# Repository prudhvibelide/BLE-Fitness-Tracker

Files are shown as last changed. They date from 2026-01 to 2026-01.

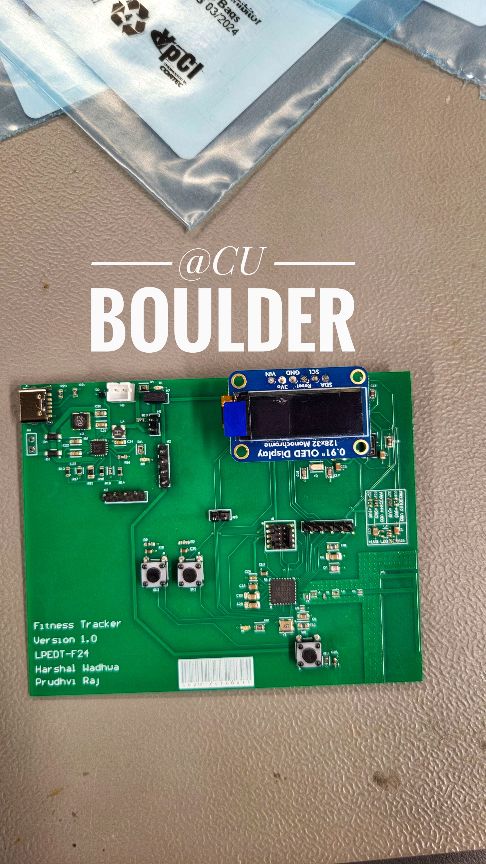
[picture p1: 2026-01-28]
PCB Board.jpg

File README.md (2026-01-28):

# BLE-Fitness-Tracker
Bluetooth based Smart Fitness Tracker using EFR32BG24 Chipset



# Developers
Prudhvi Raj Belide, Harshal Wadhwa

## Overview
This project is a bare-metal firmware bring-up for a custom wearable-style fitness tracker built around a Silicon Labs EFR32BG24. The firmware initializes board clocks and GPIO, communicates with multiple peripherals over I2C (IMU, temperature sensor, OLED), and exposes runtime telemetry over UART for validation and debugging. The goal is to prove a full embedded data path from sensor configuration and sampling to user-visible output on the display.

## Hardware
The prototype hardware is a custom PCB using an EFR32BG24 2.4 GHz SoC with I2C peripherals for sensing and display. The firmware is written to support typical wearable peripherals on the same I2C bus, including:
- Bosch BMA400 (accelerometer with step counting support)
- TI TMP117 (high-accuracy digital temperature sensor)
- SSD1306 128x64 OLED (I2C display controller)

## Firmware Summary
The firmware is implemented in C using Silicon Labs EMLIB and is structured around three layers.

Low-level drivers handle clock setup, GPIO routing, I2C transfers, and UART output. The I2C layer supports write, read, and write-then-read sequences suitable for register-mapped sensors and displays, with basic status checking and timeout protection.

Device drivers implement register-level configuration and data conversion. BMA400 is configured for periodic sampling and step counter operation, and TMP117 raw readings are converted to degrees Celsius. The SSD1306 driver writes a framebuffer to the display for stable rendering.

The application layer runs a periodic loop driven by a millisecond time base. It refreshes sensor data on a fixed cadence, updates the UI, and prints debug values over UART so you can verify I2C traffic and numeric conversions during bring-up.

## Toolchain
This project targets Silicon Labs Gecko SDK with Simplicity Studio 5.

Required:
1) Simplicity Studio 5
2) Gecko SDK for the EFR32BG24 family
3) A debug probe (onboard debugger or external) for flashing and SWD debug

## Build and Flash
Open the project in Simplicity Studio 5, make sure the correct target device is selected (EFR32BG24), then build the project using the IDE build button. Flash using the built-in Flash Programmer or by clicking Run.

If you use the command line flow, generate the project from the Simplicity Configurator (if applicable), then build with the generated project settings for your toolchain. The exact CLI steps depend on how your Simplicity project was created.

## Run and Verify
After flashing, power the board (USB-C or your board’s supply rail). The OLED should initialize and show live values such as steps and temperature if the sensors are detected on I2C.

UART is used for bring-up logs and sensor validation. Use a serial terminal at 115200 baud, 8-N-1. On Linux, a typical command looks like:
`screen /dev/ttyACM0 115200`

If you do not see logs, confirm the correct UART pins are routed in GPIO/USART configuration and that your board’s USB-UART (or external adapter) shares ground with the PCB.

## Configuration Notes
I2C device addresses, update intervals, and sampling configuration are defined in the driver/config headers. If you change the IMU range, output data rate, or step-count settings, keep the application update rate consistent with the sensor configuration so you avoid aliasing and confusing results.

If the OLED remains blank, validate the I2C pull-ups, confirm the OLED address (commonly 0x3C), and verify that the initialization sequence matches your display module.

## Repository Layout
`app.c` contains the main application loop, periodic update logic, and high-level orchestration.
`i2c_code.c/.h` contains the reusable I2C transaction layer used by all peripherals.
Other files provide board initialization, peripheral setup, and any device-specific register definitions.

## Known Limitations
This is a bring-up focused firmware and does not implement full wearable power management. For a production wearable, you would typically add deeper sleep states, interrupt-driven sampling, sensor FIFO usage where available, and aggressive duty cycling of peripherals.

## License
Use the license required by your course or team policy. If you are using Silicon Labs SDK sources, retain their headers and licensing terms where applicable.

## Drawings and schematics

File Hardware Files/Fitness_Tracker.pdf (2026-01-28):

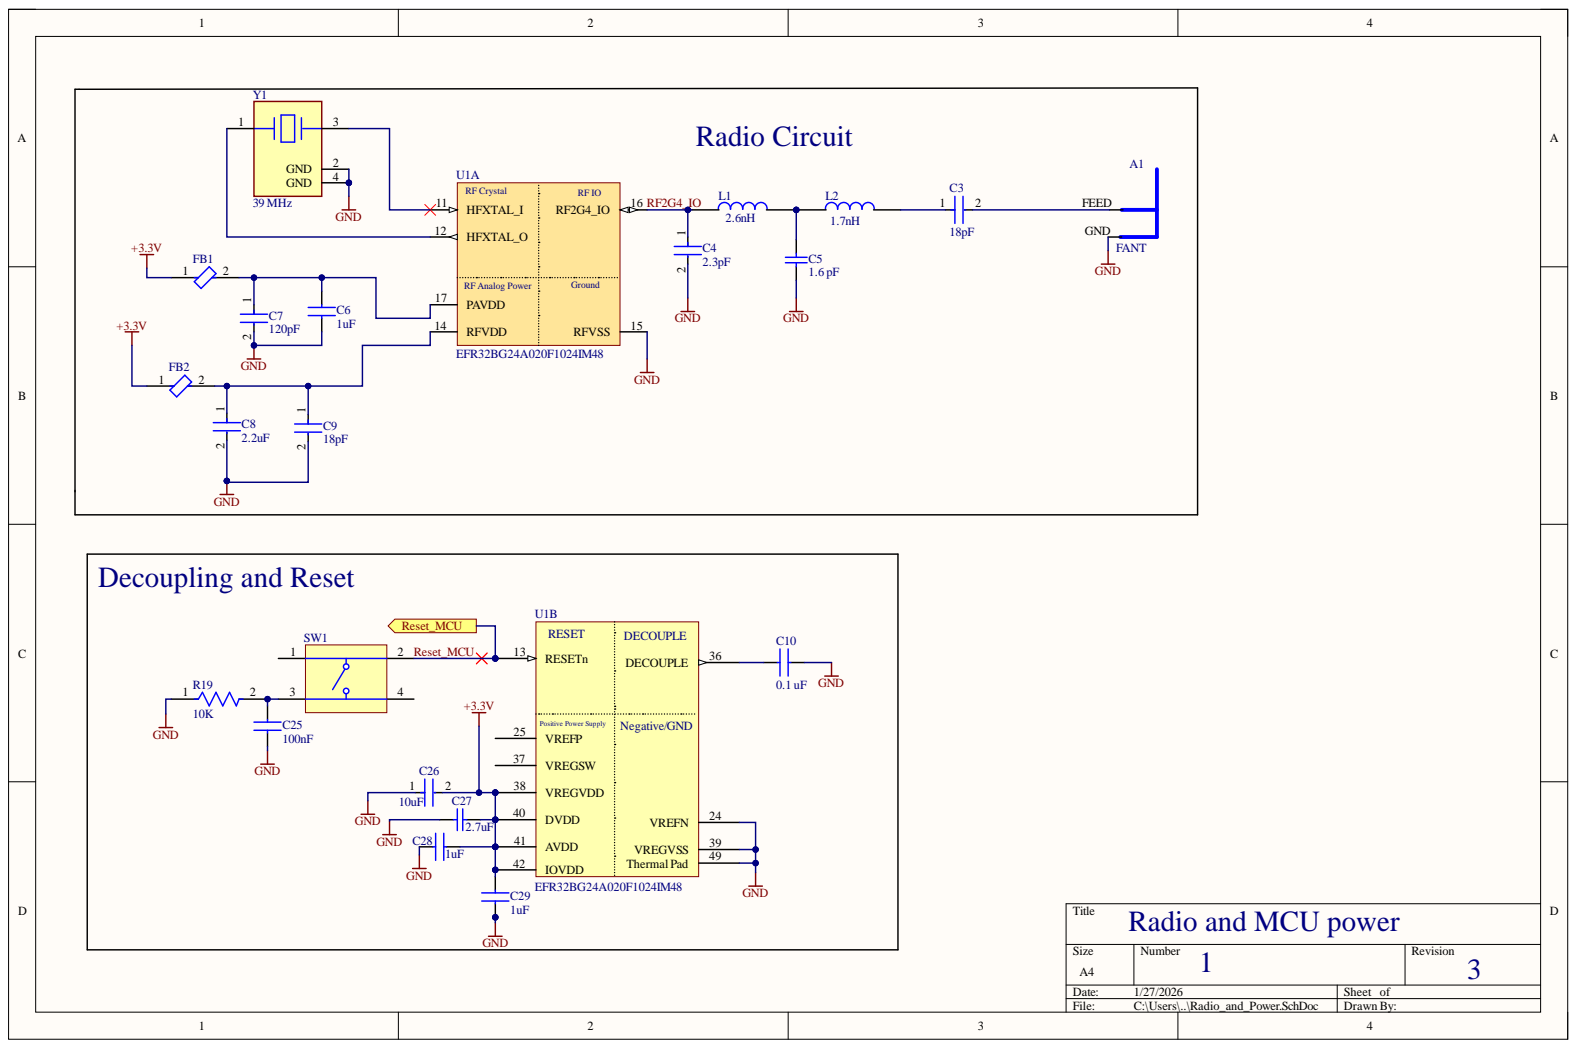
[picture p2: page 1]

Title
Radio and MCU power

Size A4 | Number 1 | Revision 3

Date: 1/27/2026 | Sheet of
File: C:\Users\..\Radio_and_Power.SchDoc | Drawn By:

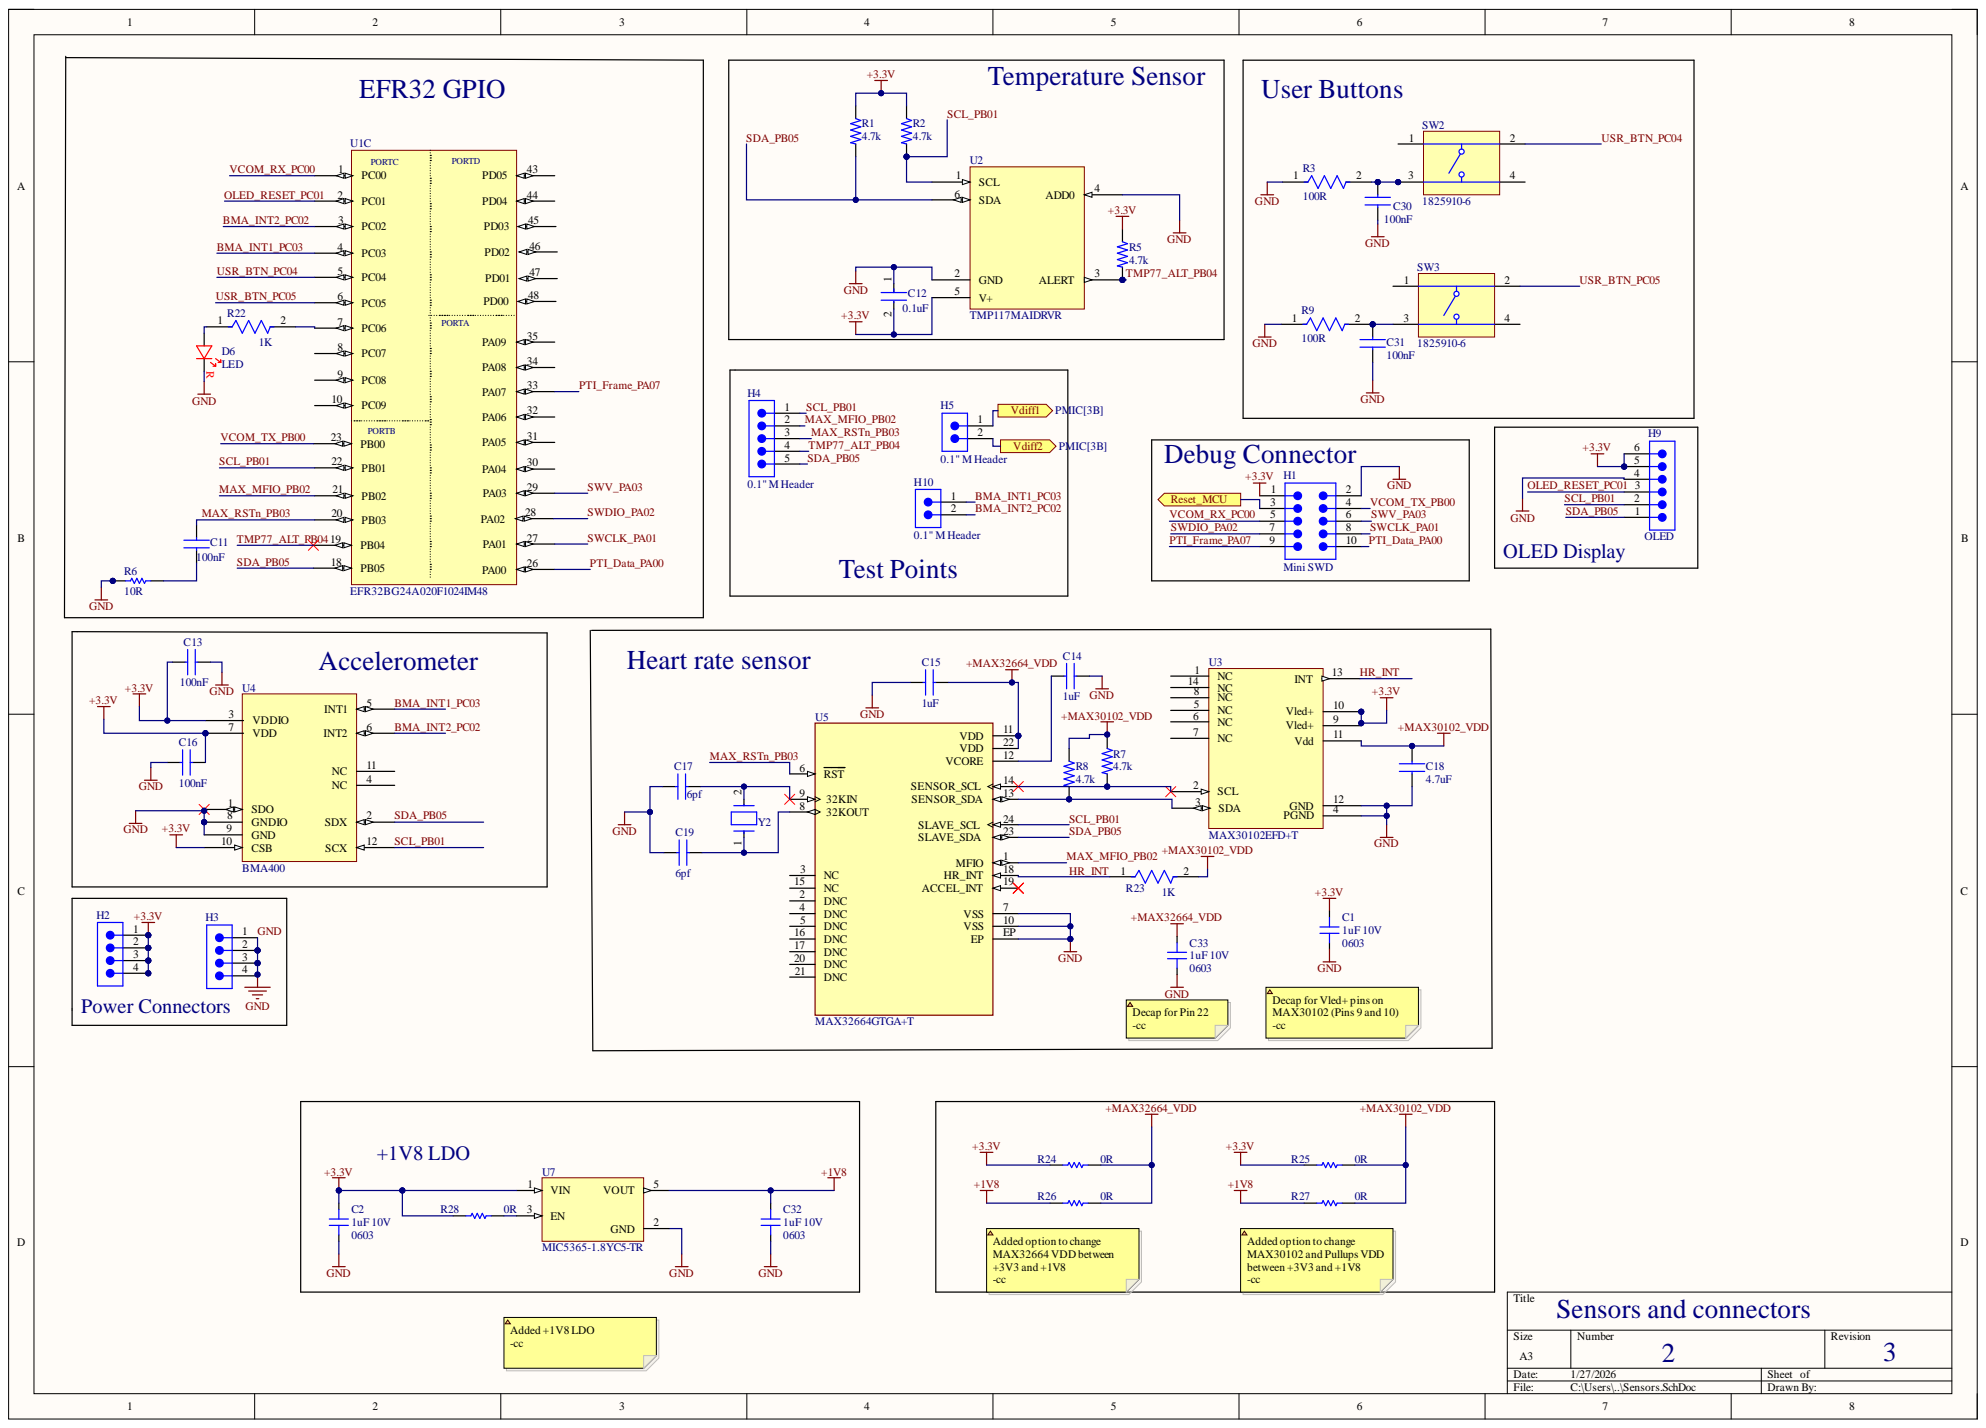
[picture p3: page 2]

Decap for Vled+ pins on
MAX30102 (Pins 9 and 10)

Added option to change
MAX30102 and Pullups VDD
between +3V3 and +1V8

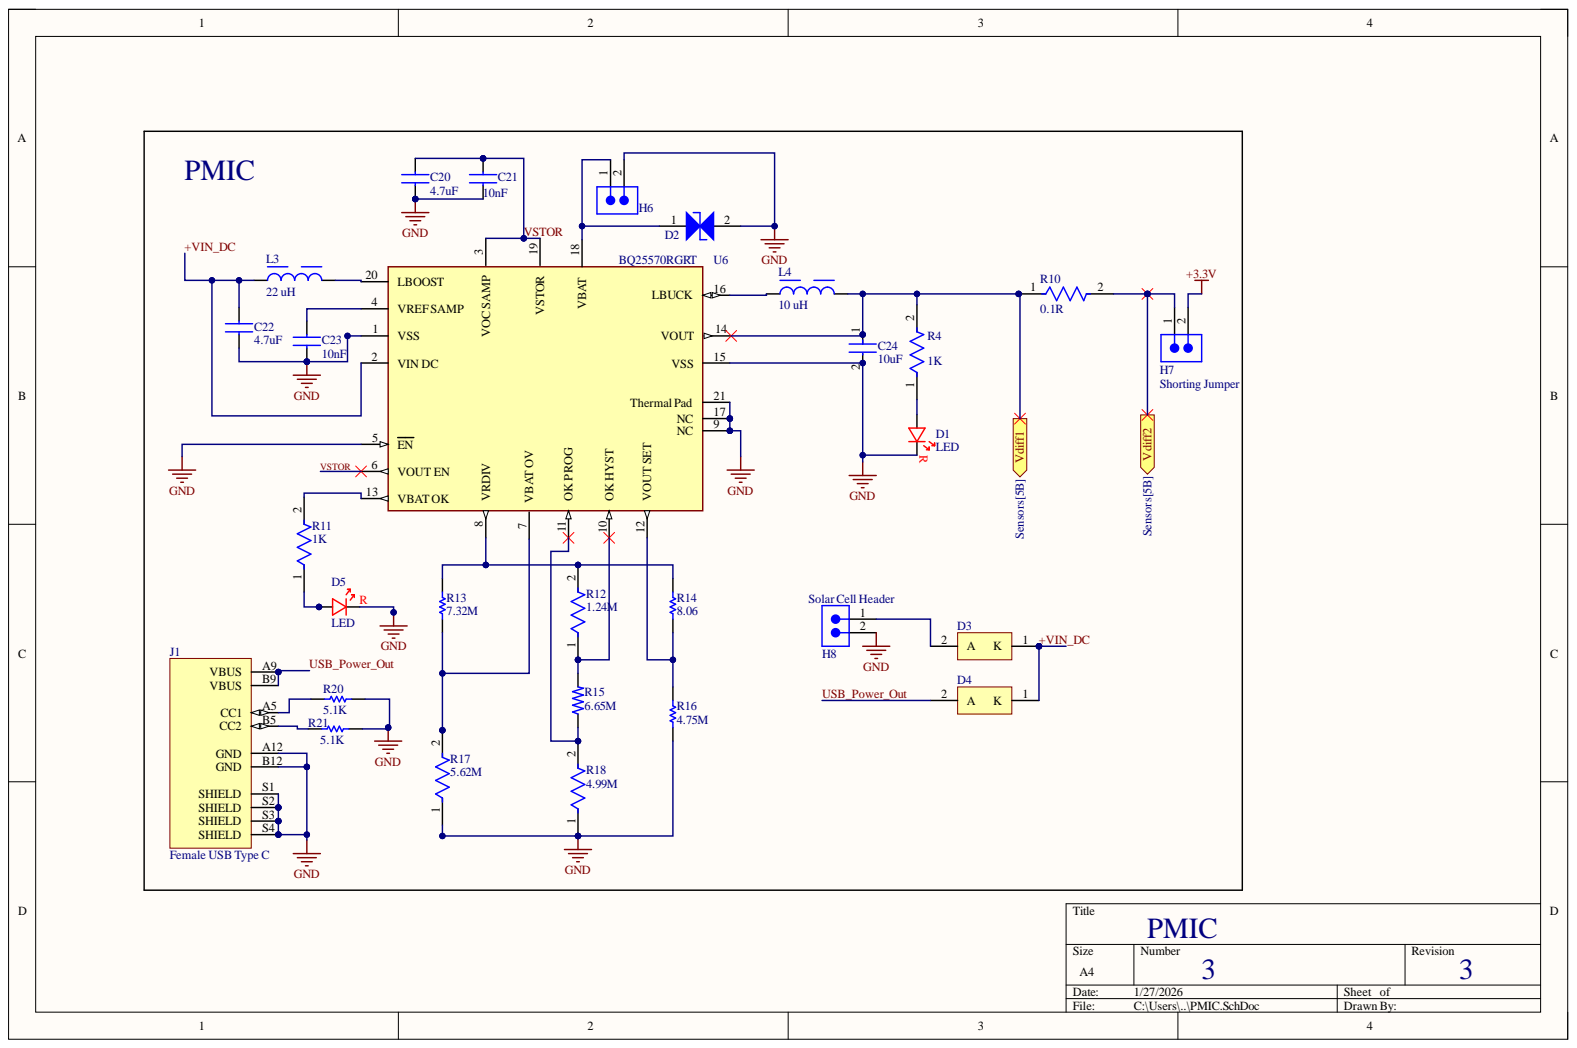
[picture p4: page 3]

Siz e A4 | Numb e r | R evisio n 3

Da te : 1/27/202 6 | She et of
File : C:\Use rs\. .\PMI C . S c hD o c | Dr awn B y :

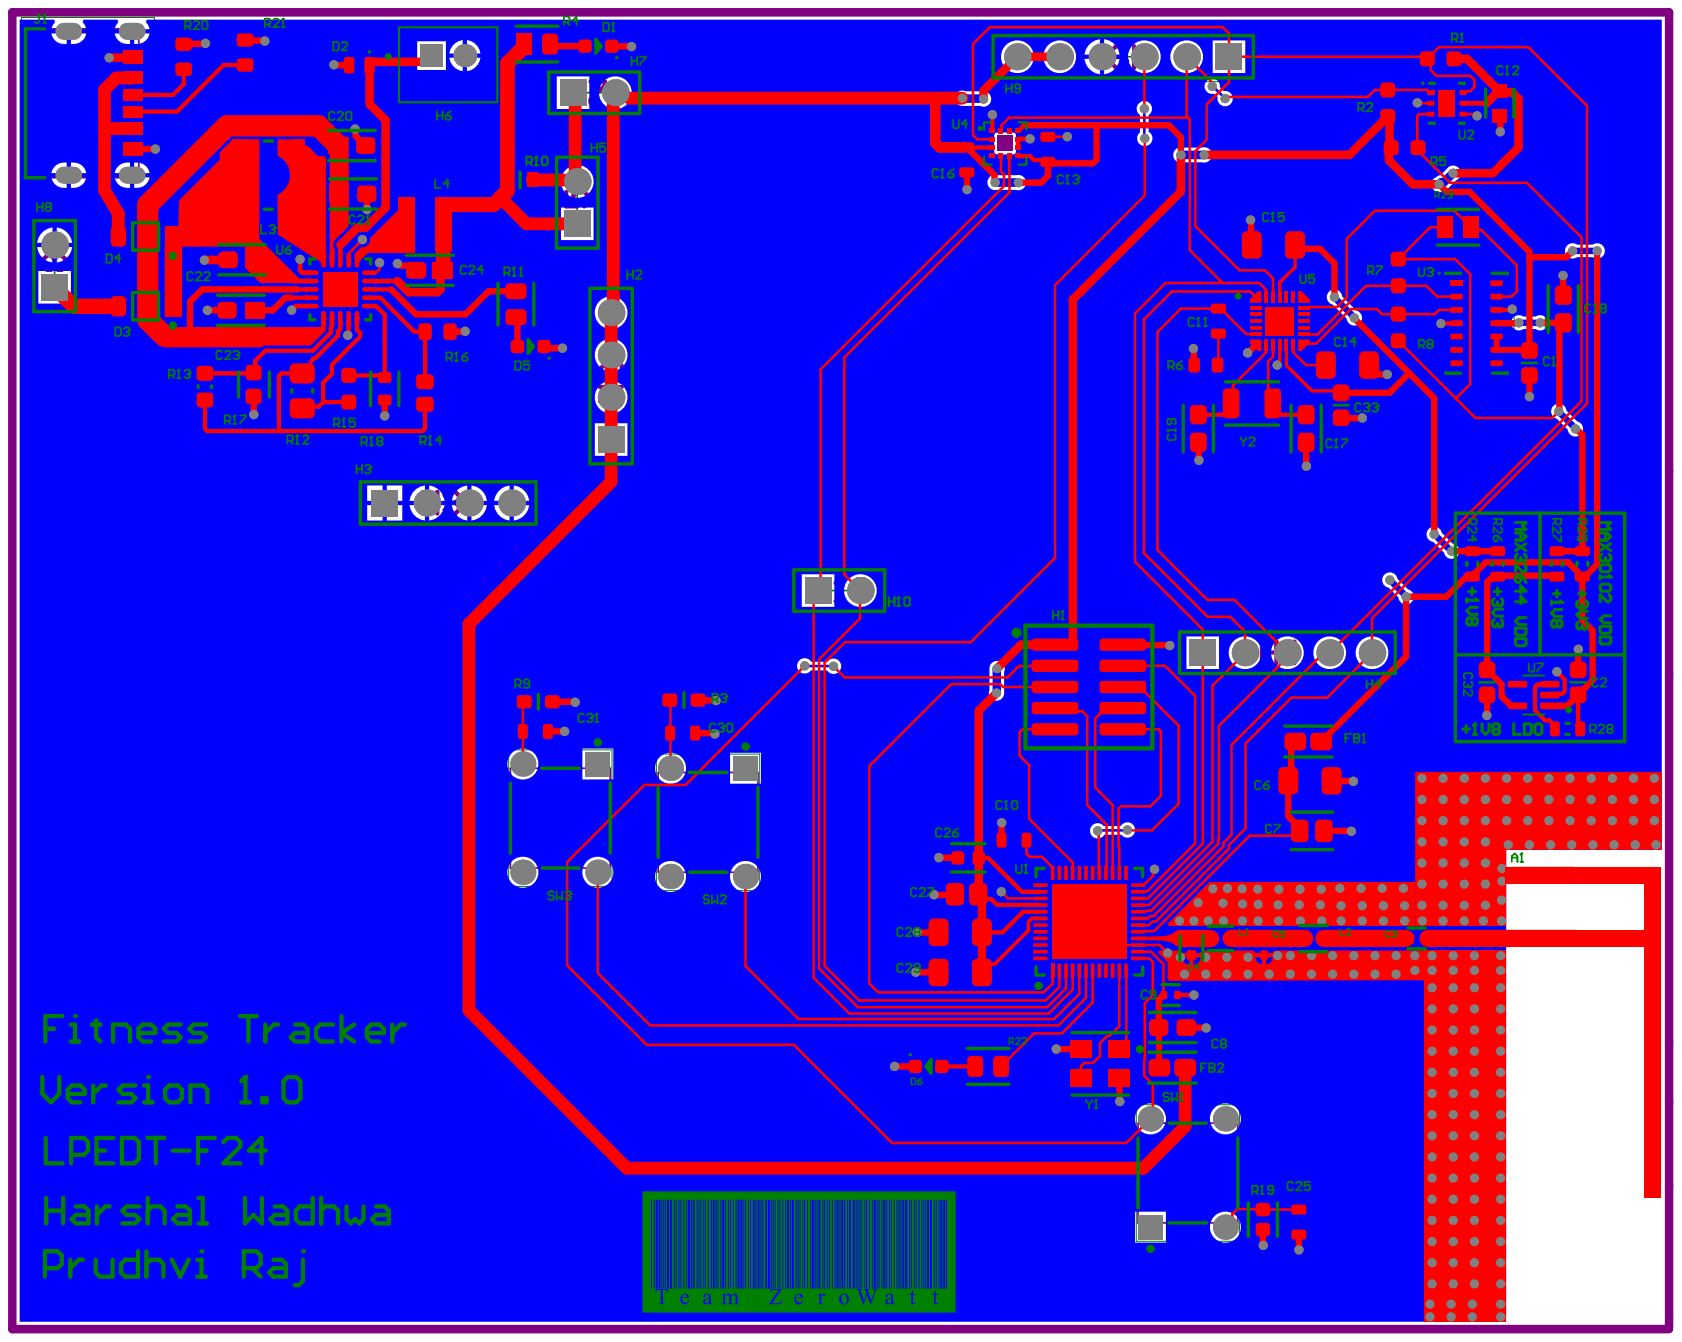
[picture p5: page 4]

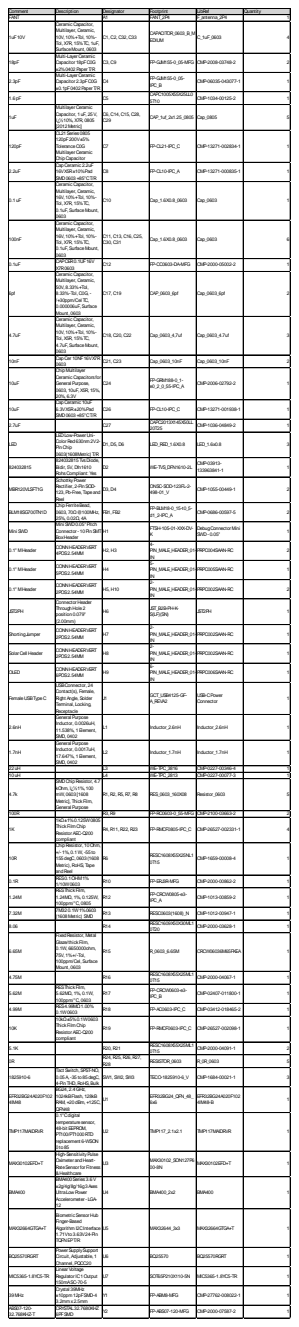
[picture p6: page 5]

1uF10V | Ceramic Capacitor, Multilayer, Ceramic, 10V, 10%+Tol, 10%-Tol, X7R, 15%TC, 1uF, SurfaceMount, 0603 | C1, C2, C32, C33 | CAPACITOR_0603_B_M EDIUM | C_1uF_0603 | 4

18pF | Multi-Layer Ceramic Capacitor 18pFC0G ±2%0402PaperT/R | C3, C9 | FP-GJM155-0_05-MFG | CMP-2008-03748-2 | 2

2.3pF | Multi-Layer Ceramic Capacitor 2.3pFC0G ±0.1pF0402PaperT/R | C4 | FP-GJM155-0_05-IPC_B | CMP-06035-043077-1 | 1

1.6pF | | C5 | CAPC1005X55X25LL0 5T10 | CMP-1034-00125-2 | 1

1uF | Multilayer Ceramic Capacitor, 1uF, 25V, ï¿½10%, X7R, 0805 [2012Metric] | C6, C14, C15, C28, C29 | CAP_1uf_2x1.25_0805 | Cap_0805 | 5

120pF | CL21Series0805 120pF200V±5% ToleranceC0G Multilayer Ceramic ChipCapacitor | C7 | FP-CL21-IPC_C | CMP-13271-002834-1 | 1

2.2uF | CapCeramic 2.2uF 16VX5R±10%Pad SMD0603+85°CT/R | C8 | FP-CL10-IPC_A | CMP-13271-000835-1 | 1

0.1uF | Ceramic Capacitor, Multilayer, Ceramic, 16V, 10%+Tol, 10%-Tol, X7R, 15%TC, 0.1uF, SurfaceMount, 0603 | C10 | Cap_1.6X0.8_0603 | Cap_0603 | 1

100nF | Ceramic Capacitor, Multilayer, Ceramic, 16V, 10%+Tol, 10%-Tol, X7R, 15%TC, 0.1uF, SurfaceMount, 0603 | C11, C13, C16, C25, C30, C31 | Cap_1.6X0.8_0603 | Cap_0603 | 6

0.1uF | CAPCER0.1UF16V X7R0603 | C12 | FP-CC0603-DA-MFG | CMP-2000-05002-2 | 1

6pf | Ceramic Capacitor, Multilayer, Ceramic, 50V, 8.33%+Tol, 8.33%-Tol, C0G, -/+30ppm/Cel TC, 0.000006uF, Surface Mount, 0603 | C17, C19 | CAP_0603_6pf | Cap_0603_6pf | 2

4.7uF | Ceramic Capacitor, Multilayer, Ceramic, 10V, 10%+Tol, 10%-Tol, X5R, 15%TC, 4.7uF, SurfaceMount, 0603 | C18, C20, C22 | Cap_0603_4,7uf | Cap_0603_4.7uf | 3

10nF | CapCer 10NF16VX7R 0603 | C21, C23 | Cap_0603_10nF | Cap_0603_10nF | 2

10uF | ChipMultilayer Ceramic Capacitorsfor General Purpose, 0603, 10uF, X5R, 15%, 20%, 6.3V | C24 | FP-GRM188-0_1-e0_2_0_55-IPC_A | CMP-2006-02792-2 | 1

10uF | CapCeramic 10uF 6.3VX5R±20%Pad SMD0603+85°CT/R | C26 | FP-CL10-IPC_C | CMP-13271-001938-1 | 1

2.7uF | | C27 | CAPC2013X145X50LL 20T25 | CMP-1036-04849-2 | 1

LED | LEDLow-Power Uni-Color Red630nm2V2-PinChip 0603(1608Metric)T/R | D1, D5, D6 | LED_RED_1.6X0.8 | LED_1.6x0.8 | 3

824032815 | 824032815TvsDiode, Bidir, 5V, Dfn1610 RohsCompliant: Yes | D2 | WE-TVS_DFN1610-2L | CMP-03913-133963841-1 | 1

MBR120VLSFT1G | SchottkyPower Rectifier, 2-PinSOD-123, Pb-Free, Tapeand Reel | D3, D4 | ONSC-SOD-123FL-2-498-01_V | CMP-1055-00449-1 | 2

BLM18SG700TN1D | ChipFerriteBead, 0603, 70Ω@100MHz, 25%, 0.02Ω, 4A | FB1, FB2 | FP-BLM18-0_15-t0_5-d1_2-IPC_A | CMP-0686-00597-5 | 2

Mini SWD | Mini SWD0.05"Pitch Connector- 10PinSMT BoxHeader | H1 | FTSH-105-01-XXX-DV-K | DebugConnector Mini SWD- 0.05" | 1

0.1" MHeader | CONNHEADERVERT 4POS2.54MM | H2, H3 | 4-PIN_MALE_HEADER_01-IN | PRPC004SAAN-RC | 2

0.1" MHeader | CONNHEADERVERT 5POS2.54MM | H4 | 5-PIN_MALE_HEADER_01-IN | PRPC005SAAN-RC | 1

0.1" MHeader | CONNHEADERVERT 2POS2.54MM | H5, H10 | 2-PIN_MALE_HEADER_01-IN | PRPC002SAAN-RC | 2

JST2PH | Connector Header ThroughHole2 position0.079" (2.00mm) | H6 | JST_B2B-PH-K-S(LF)(SN) | JST2PH | 1

ShortingJumper | CONNHEADERVERT 2POS2.54MM | H7 | 2-PIN_MALE_HEADER_01-IN | PRPC002SAAN-RC | 1

Solar Cell Header | CONNHEADERVERT 2POS2.54MM | H8 | 2-PIN_MALE_HEADER_01-IN | PRPC002SAAN-RC | 1

OLED | CONNHEADERVERT 6POS2.54MM | H9 | 6-PIN_MALE_HEADER_01-IN | PRPC006SAAN-RC | 1

FemaleUSBTypeC | USBConnector, 24 Contact(s), Female, Right Angle, Solder Terminal, Locking, Receptacle | J1 | GCT_USB4125-GF-A_REVA2 | USB-CPower Connector | 1

2.6nH | General Purpose Inductor, 0.0026uH, 11.538%, 1Element, SMD, 0402 | L1 | Inductor_2.6nH | Inductor_2.6nH | 1

1.7nH | General Purpose Inductor, 0.0017uH, 17.647%, 1Element, SMD, 0402 | L2 | Inductor_1.7nH | Inductor_1.7nH | 1

22uH | | L3 | WE-TPC_3816 | CMP-0227-00346-4 | 1
10uH | | L4 | WE-TPC_2813 | CMP-0227-00077-3 | 1
4.7k | SMDChipResistor, 4.7 kOhm, ï¿½1%, 100 mW, 0603[1608 Metric], ThickFilm, General Purpose | R1, R2, R5, R7, R8 | RES_0603_160X08 | Resistor_0603 | 5

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

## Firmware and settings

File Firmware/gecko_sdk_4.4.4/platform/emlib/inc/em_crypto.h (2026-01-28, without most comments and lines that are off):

#define EM_CRYPTO_H
#include "em_device.h"
# if defined(__GNUC__)
#  define CRYPTO_WARNINGS_NO_CAST_ALIGN \
  _Pragma("GCC diagnostic push")        \
  _Pragma("GCC diagnostic ignored \"-Wcast-align\"")
#  define CRYPTO_WARNINGS_RESET \
  _Pragma("GCC diagnostic pop")
# else
#  define CRYPTO_WARNINGS_NO_CAST_ALIGN
#  define CRYPTO_WARNINGS_RESET
# endif
#if defined(CRYPTO_COUNT) && (CRYPTO_COUNT > 0)
#include "em_bus.h"
#include "sl_common.h"
#include "em_crypto_compat.h"
#include <stdbool.h>
#include <string.h>
#ifdef __cplusplus
extern "C" {
#endif
#if defined(CRYPTO)
#define DEFAULT_CRYPTO CRYPTO
#elif defined(CRYPTO0)
#define DEFAULT_CRYPTO CRYPTO0
#endif
#define CRYPTO_DATA_SIZE_IN_BITS           (128)
#define CRYPTO_DATA_SIZE_IN_BYTES          (CRYPTO_DATA_SIZE_IN_BITS / 8)
#define CRYPTO_DATA_SIZE_IN_32BIT_WORDS    (CRYPTO_DATA_SIZE_IN_BYTES / sizeof(uint32_t))
#define CRYPTO_KEYBUF_SIZE_IN_BITS         (256)
#define CRYPTO_KEYBUF_SIZE_IN_BYTES        (CRYPTO_DDATA_SIZE_IN_BITS / 8)
#define CRYPTO_KEYBUF_SIZE_IN_32BIT_WORDS  (CRYPTO_DDATA_SIZE_IN_BYTES / sizeof(uint32_t))
#define CRYPTO_DDATA_SIZE_IN_BITS          (256)
#define CRYPTO_DDATA_SIZE_IN_BYTES         (CRYPTO_DDATA_SIZE_IN_BITS / 8)
#define CRYPTO_DDATA_SIZE_IN_32BIT_WORDS   (CRYPTO_DDATA_SIZE_IN_BYTES / sizeof(uint32_t))
#define CRYPTO_QDATA_SIZE_IN_BITS          (512)
#define CRYPTO_QDATA_SIZE_IN_BYTES         (CRYPTO_QDATA_SIZE_IN_BITS / 8)
#define CRYPTO_QDATA_SIZE_IN_32BIT_WORDS   (CRYPTO_QDATA_SIZE_IN_BYTES / sizeof(uint32_t))
#define CRYPTO_DATA260_SIZE_IN_32BIT_WORDS (9)
#define CRYPTO_SHA1_DIGEST_SIZE_IN_BITS    (160)
#define CRYPTO_SHA1_DIGEST_SIZE_IN_BYTES   (CRYPTO_SHA1_DIGEST_SIZE_IN_BITS / 8)
#define CRYPTO_SHA256_DIGEST_SIZE_IN_BITS  (256)
#define CRYPTO_SHA256_DIGEST_SIZE_IN_BYTES (CRYPTO_SHA256_DIGEST_SIZE_IN_BITS / 8)
#define CRYPTO_DDATA0_260_BITS_READ(crypto, bigint260)  CRYPTO_DData0Read260(crypto, bigint260)
#define CRYPTO_DDATA0_260_BITS_WRITE(crypto, bigint260) CRYPTO_DData0Write260(crypto, bigint260)
#define CRYPTO_SEQ_LOAD_1(crypto, a1) { \
    crypto->SEQ0 =  a1 |  (CRYPTO_CMD_INSTR_END << 8); }
#define CRYPTO_SEQ_LOAD_2(crypto, a1, a2) { \
    crypto->SEQ0 =  a1 |  (a2 << 8) |  (CRYPTO_CMD_INSTR_END << 16); }
#define CRYPTO_SEQ_LOAD_3(crypto, a1, a2, a3) { \
    crypto->SEQ0 =  a1 |  (a2 << 8) |  (a3 << 16) | (CRYPTO_CMD_INSTR_END << 24); }
#define CRYPTO_SEQ_LOAD_4(crypto, a1, a2, a3, a4) {              \
    crypto->SEQ0 =  a1 |  (a2 << 8) |  (a3 << 16) |  (a4 << 24); \
    crypto->SEQ1 =  CRYPTO_CMD_INSTR_END; }
#define CRYPTO_SEQ_LOAD_5(crypto, a1, a2, a3, a4, a5) {          \
    crypto->SEQ0 =  a1 |  (a2 << 8) |  (a3 << 16) |  (a4 << 24); \
    crypto->SEQ1 =  a5 |  (CRYPTO_CMD_INSTR_END << 8); }
#define CRYPTO_SEQ_LOAD_6(crypto, a1, a2, a3, a4, a5, a6) {      \
    crypto->SEQ0 =  a1 |  (a2 << 8) |  (a3 << 16) |  (a4 << 24); \
    crypto->SEQ1 =  a5 |  (a6 << 8) |  (CRYPTO_CMD_INSTR_END << 16); }
#define CRYPTO_SEQ_LOAD_7(crypto, a1, a2, a3, a4, a5, a6, a7) {  \
    crypto->SEQ0 =  a1 |  (a2 << 8) |  (a3 << 16) |  (a4 << 24); \
    crypto->SEQ1 =  a5 |  (a6 << 8) |  (a7 << 16) |  (CRYPTO_CMD_INSTR_END << 24); }
#define CRYPTO_SEQ_LOAD_8(crypto, a1, a2, a3, a4, a5, a6, a7, a8) { \
    crypto->SEQ0 =  a1 |  (a2 << 8) |  (a3 << 16) |  (a4 << 24);    \
    crypto->SEQ1 =  a5 |  (a6 << 8) |  (a7 << 16) |  (a8 << 24);    \
    crypto->SEQ2 =  CRYPTO_CMD_INSTR_END; }
#define CRYPTO_SEQ_LOAD_9(crypto, a1, a2, a3, a4, a5, a6, a7, a8, a9) { \
    crypto->SEQ0 =  a1 |  (a2 << 8) |  (a3 << 16) |  (a4 << 24);        \
    crypto->SEQ1 =  a5 |  (a6 << 8) |  (a7 << 16) |  (a8 << 24);        \
    crypto->SEQ2 =  a9 | (CRYPTO_CMD_INSTR_END << 8); }
#define CRYPTO_SEQ_LOAD_10(crypto, a1, a2, a3, a4, a5, a6, a7, a8, a9, a10) { \
    crypto->SEQ0 =  a1 |  (a2 << 8) |  (a3 << 16) |  (a4 << 24);              \
    crypto->SEQ1 =  a5 |  (a6 << 8) |  (a7 << 16) |  (a8 << 24);              \
    crypto->SEQ2 =  a9 | (a10 << 8) | (CRYPTO_CMD_INSTR_END << 16); }
#define CRYPTO_SEQ_LOAD_11(crypto, a1, a2, a3, a4, a5, a6, a7, a8, a9, a10, a11) { \
    crypto->SEQ0 =  a1 |  (a2 << 8) |  (a3 << 16) |  (a4 << 24);                   \
    crypto->SEQ1 =  a5 |  (a6 << 8) |  (a7 << 16) |  (a8 << 24);                   \
    crypto->SEQ2 =  a9 | (a10 << 8) | (a11 << 16) | (CRYPTO_CMD_INSTR_END << 24); }
#define CRYPTO_SEQ_LOAD_12(crypto, a1, a2, a3, a4, a5, a6, a7, a8, a9, a10, a11, a12) { \
    crypto->SEQ0 =  a1 |  (a2 << 8) |  (a3 << 16) |  (a4 << 24);                        \
    crypto->SEQ1 =  a5 |  (a6 << 8) |  (a7 << 16) |  (a8 << 24);                        \
    crypto->SEQ2 =  a9 | (a10 << 8) | (a11 << 16) | (a12 << 24);                        \
    crypto->SEQ3 = CRYPTO_CMD_INSTR_END; }
#define CRYPTO_SEQ_LOAD_13(crypto, a1, a2, a3, a4, a5, a6, a7, a8, a9, a10, a11, a12, a13) { \
    crypto->SEQ0 =  a1 |  (a2 << 8) |  (a3 << 16) |  (a4 << 24);                             \
    crypto->SEQ1 =  a5 |  (a6 << 8) |  (a7 << 16) |  (a8 << 24);                             \
    crypto->SEQ2 =  a9 | (a10 << 8) | (a11 << 16) | (a12 << 24);                             \
    crypto->SEQ3 = a13 | (CRYPTO_CMD_INSTR_END << 8); }
#define CRYPTO_SEQ_LOAD_14(crypto, a1, a2, a3, a4, a5, a6, a7, a8, a9, a10, a11, a12, a13, a14) { \
    crypto->SEQ0 =  a1 |  (a2 << 8) |  (a3 << 16) |  (a4 << 24);                                  \
    crypto->SEQ1 =  a5 |  (a6 << 8) |  (a7 << 16) |  (a8 << 24);                                  \
    crypto->SEQ2 =  a9 | (a10 << 8) | (a11 << 16) | (a12 << 24);                                  \
    crypto->SEQ3 = a13 | (a14 << 8) | (CRYPTO_CMD_INSTR_END << 16); }
#define CRYPTO_SEQ_LOAD_15(crypto, a1, a2, a3, a4, a5, a6, a7, a8, a9, a10, a11, a12, a13, a14, a15) { \
    crypto->SEQ0 =  a1 |  (a2 << 8) |  (a3 << 16) |  (a4 << 24);                                       \
    crypto->SEQ1 =  a5 |  (a6 << 8) |  (a7 << 16) |  (a8 << 24);                                       \
    crypto->SEQ2 =  a9 | (a10 << 8) | (a11 << 16) | (a12 << 24);                                       \
    crypto->SEQ3 = a13 | (a14 << 8) | (a15 << 16) | (CRYPTO_CMD_INSTR_END << 24); }
#define CRYPTO_SEQ_LOAD_16(crypto, a1, a2, a3, a4, a5, a6, a7, a8, a9, a10, a11, a12, a13, a14, a15, a16) { \
    crypto->SEQ0 =  a1 |  (a2 << 8) |  (a3 << 16) |  (a4 << 24);                                            \
    crypto->SEQ1 =  a5 |  (a6 << 8) |  (a7 << 16) |  (a8 << 24);                                            \
    crypto->SEQ2 =  a9 | (a10 << 8) | (a11 << 16) | (a12 << 24);                                            \
    crypto->SEQ3 = a13 | (a14 << 8) | (a15 << 16) | (a16 << 24);                                            \
    crypto->SEQ4 = CRYPTO_CMD_INSTR_END; }
#define CRYPTO_SEQ_LOAD_17(crypto, a1, a2, a3, a4, a5, a6, a7, a8, a9, a10, a11, a12, a13, a14, a15, a16, a17) { \
    crypto->SEQ0 =  a1 |  (a2 << 8) |  (a3 << 16) |  (a4 << 24);                                                 \
    crypto->SEQ1 =  a5 |  (a6 << 8) |  (a7 << 16) |  (a8 << 24);                                                 \
    crypto->SEQ2 =  a9 | (a10 << 8) | (a11 << 16) | (a12 << 24);                                                 \
    crypto->SEQ3 = a13 | (a14 << 8) | (a15 << 16) | (a16 << 24);                                                 \
    crypto->SEQ4 = a17 | (CRYPTO_CMD_INSTR_END << 8); }
#define CRYPTO_SEQ_LOAD_18(crypto, a1, a2, a3, a4, a5, a6, a7, a8, a9, a10, a11, a12, a13, a14, a15, a16, a17, a18) { \
    crypto->SEQ0 =  a1 |  (a2 << 8) |  (a3 << 16) |  (a4 << 24);                                                      \
    crypto->SEQ1 =  a5 |  (a6 << 8) |  (a7 << 16) |  (a8 << 24);                                                      \
    crypto->SEQ2 =  a9 | (a10 << 8) | (a11 << 16) | (a12 << 24);                                                      \
    crypto->SEQ3 = a13 | (a14 << 8) | (a15 << 16) | (a16 << 24);                                                      \
    crypto->SEQ4 = a17 | (a18 << 8) | (CRYPTO_CMD_INSTR_END << 16); }
#define CRYPTO_SEQ_LOAD_19(crypto, a1, a2, a3, a4, a5, a6, a7, a8, a9, a10, a11, a12, a13, a14, a15, a16, a17, a18, a19) { \
    crypto->SEQ0 =  a1 |  (a2 << 8) |  (a3 << 16) |  (a4 << 24);                                                           \
    crypto->SEQ1 =  a5 |  (a6 << 8) |  (a7 << 16) |  (a8 << 24);                                                           \
    crypto->SEQ2 =  a9 | (a10 << 8) | (a11 << 16) | (a12 << 24);                                                           \
    crypto->SEQ3 = a13 | (a14 << 8) | (a15 << 16) | (a16 << 24);                                                           \
    crypto->SEQ4 = a17 | (a18 << 8) | (a19 << 16) | (CRYPTO_CMD_INSTR_END << 24); }
#define CRYPTO_SEQ_LOAD_20(crypto, a1, a2, a3, a4, a5, a6, a7, a8, a9, a10, a11, a12, a13, a14, a15, a16, a17, a18, a19, a20) { \
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

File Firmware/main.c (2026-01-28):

/***************************************************************************//**
 * @file main.c
 * @brief main() function.
 *******************************************************************************
 * # License
 * <b>Copyright 2020 Silicon Laboratories Inc. www.silabs.com</b>
 *******************************************************************************
 *
 * The licensor of this software is Silicon Laboratories Inc. Your use of this
 * software is governed by the terms of Silicon Labs Master Software License
 * Agreement (MSLA) available at
 * www.silabs.com/about-us/legal/master-software-license-agreement. This
 * software is distributed to you in Source Code format and is governed by the
 * sections of the MSLA applicable to Source Code.
 *
 ******************************************************************************/
#include "sl_component_catalog.h"
#include "sl_system_init.h"
#include "app.h"
#include "sl_system_process_action.h"
#include "em_gpio.h"
#include "em_usart.h"
#include "em_cmu.h"
#include "em_timer.h"
#include "i2c_code.h"
#include "em_gpio.h"
#include <string.h>
#include <stdio.h>
#include <stdlib.h>

// Timer configuration
#define TIMER_FREQ  1000 // 1 kHz for 1 ms resolution

volatile bool delayComplete = false;

// Global variables for time tracking
volatile uint8_t current_hours = 12;   // Start at 16:05
volatile uint8_t current_minutes = 01;
volatile uint8_t current_seconds = 0;
volatile uint16_t ms_counter = 0;

#define SSD1306_ADDR 0x3C
#define SSD1306_CMD  0x00
#define SSD1306_DATA 0x40

#define SSD1306_WIDTH  128
#define SSD1306_HEIGHT 64

// SSD1306 commands
#define SSD1306_DISPLAYOFF          0xAE
#define SSD1306_SETDISPLAYCLOCKDIV 0xD5
#define SSD1306_SETMULTIPLEX       0xA8
#define SSD1306_SETDISPLAYOFFSET   0xD3
#define SSD1306_SETSTARTLINE       0x40
#define SSD1306_CHARGEPUMP         0x8D
#define SSD1306_MEMORYMODE         0x20
#define SSD1306_SEGREMAP           0xA0
#define SSD1306_COMSCANDEC         0xC8
#define SSD1306_SETCOMPINS         0xDA
#define SSD1306_SETCONTRAST        0x81
#define SSD1306_SETPRECHARGE       0xD9
#define SSD1306_SETVCOMDETECT      0xDB
#define SSD1306_DISPLAYALLON_RESUME 0xA4
#define SSD1306_NORMALDISPLAY      0xA6
#define SSD1306_DISPLAYON          0xAF

// Display buffer
static uint8_t SSD1306_Buffer[SSD1306_WIDTH * SSD1306_HEIGHT / 8];

const uint8_t font5x8[] = {
    0x00, 0x00, 0x00, 0x00, 0x00, // Space (20)
    0x3E, 0x51, 0x49, 0x45, 0x3E, // 0
    0x00, 0x42, 0x7F, 0x40, 0x00, // 1
    0x42, 0x61, 0x51, 0x49, 0x46, // 2
    0x21, 0x41, 0x45, 0x4B, 0x31, // 3
    0x18, 0x14, 0x12, 0x7F, 0x10, // 4
    0x27, 0x45, 0x45, 0x45, 0x39, // 5
    0x3C, 0x4A, 0x49, 0x49, 0x30, // 6
    0x01, 0x71, 0x09, 0x05, 0x03, // 7
    0x36, 0x49, 0x49, 0x49, 0x36, // 8
    0x06, 0x49, 0x49, 0x29, 0x1E, // 9
    0x00, 0x60, 0x60, 0x00, 0x00, // . (2E)
    0x00, 0x66, 0x66, 0x00, 0x00, // : (3A)
    0x00, 0x00, 0x00, 0x00, 0x00, // Space
    0x7F, 0x09, 0x09, 0x09, 0x06, // P
    0x7F, 0x49, 0x49, 0x49, 0x41, // E
    0x7F, 0x02, 0x0C, 0x02, 0x7F, // M
    0x01, 0x01, 0x7F, 0x01, 0x01, // T
    0x3F, 0x40, 0x40, 0x40, 0x3F, // U
    0x7F, 0x08, 0x14, 0x22, 0x41, // K
    0x7F, 0x08, 0x08, 0x08, 0x7F, // H
    0x7F, 0x41, 0x41, 0x22, 0x1C, // D
    0x3E, 0x41, 0x41, 0x41, 0x22, // C
    0x7F, 0x40, 0x40, 0x40, 0x40, // L
    0x7F, 0x02, 0x0C, 0x02, 0x7F, // N
    0x7F, 0x09, 0x19, 0x29, 0x46, // R
    0x46, 0x49, 0x49, 0x49, 0x31, // S
    0x7E, 0x09, 0x09, 0x09, 0x7E, // A
    0x7F, 0x49, 0x49, 0x49, 0x36  // B
};


// Modified symbol patterns with clearer and larger designs
const uint8_t custom_symbols[] = {
    // Temperature symbol (thermometer) - 8x8 pattern
    0x18,  // ...##...
    0x24,  // ..#..#..
    0x24,  // ..#..#..
    0x24,  // ..#..#..
    0x3C,  // ..####..
    0x3C,  // ..####..
    0x3C,  // ..####..
    0x18,  // ...##...

    // Steps symbol (shoe) - 8x8 pattern
       0x1E,  // ...####.
       0x3F,  // ..######
       0x3F,  // ..######
       0x7E,  // .######.
       0x7C,  // .#####..
       0x78,  // .####...
       0x70,  // .###....
       0x60,  // .##.....

    // Heart symbol - 8x8 pattern (unchanged)
    0x66,  // .##..##.
    0xFF,  // ########
    0xFF,  // ########
    0x7E,  // .######.
    0x3C,  // ..####..
    0x18,  // ...##...
    0x00,  // ........
    0x00   // ........
};

  void uart_init(void) {
      // Enable clock for GPIO and USART0
    CMU_ClockEnable(cmuClock_GPIO, true);
      CMU_ClockEnable(cmuClock_USART0, true);

      // Configure PB02 as TX (push-pull) and PB03 as RX (input)
      GPIO_PinModeSet(gpioPortB, 2, gpioModePushPull, 1); // TX
      GPIO_PinModeSet(gpioPortB, 3, gpioModeInput, 0);    // RX

      // Initialize USART with default settings
      USART_InitAsync_TypeDef init = USART_INITASYNC_DEFAULT;
      init.baudrate = 115200;  // Set baud rate
      USART_InitAsync(USART0, &init);

      // Route USART0 TX and RX to PB02 and PB03
      GPIO->USARTROUTE[0].TXROUTE = (gpioPortB << _GPIO_USART_TXROUTE_PORT_SHIFT) | (2 << _GPIO_USART_TXROUTE_PIN_SHIFT);
      GPIO->USARTROUTE[0].RXROUTE = (gpioPortB << _GPIO_USART_RXROUTE_PORT_SHIFT) | (3 << _GPIO_USART_RXROUTE_PIN_SHIFT);
      GPIO->USARTROUTE[0].ROUTEEN = GPIO_USART_ROUTEEN_TXPEN | GPIO_USART_ROUTEEN_RXPEN;

      // Enable USART0
      USART_Enable(USART0, usartEnable);
}

// Function to send a single character over UART
void uart_send_char(char c) {
    // Wait until the transmit buffer is empty
    while (!(USART0->STATUS & USART_STATUS_TXBL));

    // Transmit the character
    USART_Tx(USART0, c);
}

// Function to send a string over UART
void uart_send_string(const char *str) {
    while (*str) {
        uart_send_char(*str++);
    }
}

char buffer[12];  // Buffer to hold the string representation of the number

// Function to send a number as a string over UART
void uart_send_number(int number) {
 //   char buffer[12];  // Buffer to hold the string representation of the number
    sprintf(buffer, "%d", number);
    uart_send_string(buffer);
}


void timer_init(void) {
    // Enable clock for TIMER0
    CMU_ClockEnable(cmuClock_TIMER0, true);

    // Initialize the timer
    TIMER_Init_TypeDef timerInit = TIMER_INIT_DEFAULT;
   // timerInit.prescale = timerPrescale256; // Adjust prescaler if necessary
    timerInit.prescale = timerPrescale16; // Set prescaler to 16 for slower counting
    TIMER_Init(TIMER0, &timerInit);

    // Set up the timer for 1 ms overflow
    uint32_t topValue = (CMU_ClockFreqGet(cmuClock_SYSCLK) / 16 / TIMER_FREQ) - 1;
    TIMER_TopSet(TIMER0, topValue);


    // Enable timer interrupt
    TIMER_IntClear(TIMER0, TIMER_IF_OF); // Clear overflow flag
    TIMER_IntEnable(TIMER0, TIMER_IF_OF); // Enable overflow interrupt
    NVIC_EnableIRQ(TIMER0_IRQn); // Enable TIMER0 interrupt in NVIC
}

// Modified timer interrupt handler
void TIMER0_IRQHandler(void) {
    // Clear the interrupt flag
    TIMER_IntClear(TIMER0, TIMER_IF_OF);
    delayComplete = true;

    // Since timer is set for 1ms intervals
    ms_counter++;

    // Check if a second has passed
    if (ms_counter >= 1000) {
        ms_counter = 0;
        current_seconds++;

        // Update minutes
        if (current_seconds >= 60) {
            current_seconds = 0;
            current_minutes++;

            // Update hours
            if (current_minutes >= 60) {
                current_minutes = 0;
                current_hours++;

                // Wrap hours at 24
                if (current_hours >= 24) {
                    current_hours = 0;
                }
            }
        }
    }
}

void blocking_delay_ms(uint32_t ms) {
    delayComplete = false; // Reset delay completion flag

    // Start the timer
    TIMER_CounterSet(TIMER0, 0); // Reset the timer counter
    TIMER_Enable(TIMER0, true);   // Enable the timer

    // Wait for the delay to complete
    for (uint32_t i = 0; i < ms; i++) {
        while (!delayComplete); // Wait for the timer to overflow
        delayComplete = false;  // Reset for the next iteration
    }

    TIMER_Enable(TIMER0, false); // Disable the timer after the delay
}

void reverse(char* str, int len) {
    int start = 0;
    int end = len - 1;
    while (start < end) {
        char temp = str[start];
        str[start] = str[end];
        str[end] = temp;
        start++;
        end--;
    }
}

// Helper function to convert an integer to a string
int intToStr(int num, char* str, int minDigits) {
    int i = 0;
    int isNegative = 0;

    // Handle negative numbers
    if (num < 0) {
        isNegative = 1;
        num = -num;
    }

    // Convert each digit to character
    do {
        str[i++] = (num % 10) + '0';
        num /= 10;
    } while (num);

    // Add leading zeros if needed
    while (i < minDigits) {
        str[i++] = '0';
    }

    // Add negative sign if necessary
    if (isNegative) {
        str[i++] = '-';
    }

    // Reverse the string since we built it backward
    reverse(str, i);

    // Return the length of the string
    return i;
}

// Function to convert a floating-point number to a string
void floatToStr(float n, char* res, int precision) {
    // Extract integer part
    int intPart = (int)n;

    // Extract fractional part
    float fracPart = n - (float)intPart;

    // Convert integer part to string
    int i = intToStr(intPart, res, 0);

    // Add the decimal point
    res[i] = '.';
    i++;

    // Handle fractional part
    for (int j = 0; j < precision; j++) {
        fracPart *= 10;
    }

    int fracIntPart = (int)(fracPart);

    // Convert fractional part to string
    i+= intToStr(fracIntPart, res + i, precision);

    // Add \r\n at the end
//        res[i++] = '\r';
//        res[i++] = '\n';

        // Null-terminate the string
        res[i] = '\0';
}


// Display buffer
static uint8_t SSD1306_Buffer[SSD1306_WIDTH * SSD1306_HEIGHT / 8];

// Function to write a command to SSD1306
void SSD1306_WriteCommand(uint8_t command) {
    I2C_writeByte(SSD1306_ADDR, SSD1306_CMD, command);
}

// Function to write data to SSD1306
void SSD1306_WriteData(uint8_t data) {
    I2C_writeByte(SSD1306_ADDR, SSD1306_DATA, data);
}

// Initialize the display
void SSD1306_Init(void) {
    blocking_delay_ms(100);  // Wait for VDD to stabilize

    SSD1306_WriteCommand(SSD1306_DISPLAYOFF);
    SSD1306_WriteCommand(SSD1306_SETDISPLAYCLOCKDIV);
    SSD1306_WriteCommand(0x80);  // Suggested ratio

    SSD1306_WriteCommand(SSD1306_SETMULTIPLEX);
    SSD1306_WriteCommand(0x3F);  // 64 MUX for 128x64

    SSD1306_WriteCommand(SSD1306_SETDISPLAYOFFSET);
    SSD1306_WriteCommand(0x00);

    SSD1306_WriteCommand(SSD1306_SETSTARTLINE | 0x00);

    SSD1306_WriteCommand(SSD1306_CHARGEPUMP);
    SSD1306_WriteCommand(0x14);  // Enable charge pump

    SSD1306_WriteCommand(SSD1306_MEMORYMODE);
    SSD1306_WriteCommand(0x00);  // Horizontal addressing

    SSD1306_WriteCommand(SSD1306_SEGREMAP | 0x01);
    SSD1306_WriteCommand(SSD1306_COMSCANDEC);

    SSD1306_WriteCommand(SSD1306_SETCOMPINS);
    SSD1306_WriteCommand(0x12);

    SSD1306_WriteCommand(SSD1306_SETCONTRAST);
    SSD1306_WriteCommand(0xCF);

    SSD1306_WriteCommand(SSD1306_SETPRECHARGE);
    SSD1306_WriteCommand(0xF1);

    SSD1306_WriteCommand(SSD1306_SETVCOMDETECT);
    SSD1306_WriteCommand(0x40);

    SSD1306_WriteCommand(SSD1306_DISPLAYALLON_RESUME);
    SSD1306_WriteCommand(SSD1306_NORMALDISPLAY);
    SSD1306_WriteCommand(SSD1306_DISPLAYON);
}

// Clear the display buffer
void SSD1306_Clear(void) {
    memset(SSD1306_Buffer, 0, sizeof(SSD1306_Buffer));
}

// Update the display with the buffer contents
void SSD1306_UpdateDisplay(void) {
    SSD1306_WriteCommand(0x20); // Set Memory Addressing Mode
    SSD1306_WriteCommand(0x00); // Horizontal addressing mode

    SSD1306_WriteCommand(0x21); // Set Column Address
    SSD1306_WriteCommand(0x00); // Start at column 0
    SSD1306_WriteCommand(SSD1306_WIDTH - 1);

    SSD1306_WriteCommand(0x22); // Set Page Address
    SSD1306_WriteCommand(0x00); // Start at page 0
    SSD1306_WriteCommand(7);    // End at page 7

    // Write the entire buffer
    for (uint16_t i = 0; i < sizeof(SSD1306_Buffer); i++) {
        SSD1306_WriteData(SSD1306_Buffer[i]);
    }
}

// Modified Clear Display function
void SSD1306_ClearDisplay(void) {
    // Clear the buffer
    memset(SSD1306_Buffer, 0, sizeof(SSD1306_Buffer));

    // Reset display addressing mode
    SSD1306_WriteCommand(0x20);  // Set Memory Addressing Mode
    SSD1306_WriteCommand(0x00);  // Horizontal addressing mode

    // Set column address range
    SSD1306_WriteCommand(0x21);  // Set Column Address
    SSD1306_WriteCommand(0x00);  // Start at column 0
    SSD1306_WriteCommand(SSD1306_WIDTH - 1);  // End at last column

    // Set page address range
    SSD1306_WriteCommand(0x22);  // Set Page Address
    SSD1306_WriteCommand(0x00);  // Start at page 0
    SSD1306_WriteCommand(7);     // End at page 7

    // Write zeros to all display memory
    for (uint16_t i = 0; i < (SSD1306_WIDTH * SSD1306_HEIGHT / 8); i++) {
        SSD1306_WriteData(0x00);
    }
}

// Draw a pixel in the buffer
void SSD1306_DrawPixel(uint8_t x, uint8_t y) {
    if (x >= SSD1306_WIDTH || y >= SSD1306_HEIGHT) return;

    // Calculate the byte position in the buffer
    uint16_t byte_pos = x + (y / 8) * SSD1306_WIDTH;
    // Calculate the bit position within the byte
    uint8_t bit_pos = y % 8;

    // Set the pixel
    SSD1306_Buffer[byte_pos] |= (1 << bit_pos);
}

// Example function to draw a simple pattern
void SSD1306_DrawTestPattern(void) {
    SSD1306_Clear();

    // Draw a border
    for (uint8_t x = 0; x < SSD1306_WIDTH; x++) {
        SSD1306_DrawPixel(x, 0);
        SSD1306_DrawPixel(x, SSD1306_HEIGHT-1);
    }
    for (uint8_t y = 0; y < SSD1306_HEIGHT; y++) {
        SSD1306_DrawPixel(0, y);
        SSD1306_DrawPixel(SSD1306_WIDTH-1, y);
    }

    SSD1306_UpdateDisplay();
}

void SSD1306_DrawChar(uint8_t x, uint8_t y, char ch) {
    int index;

    if (ch >= '0' && ch <= '9') {
        index = 1 + (ch - '0');
    } else if (ch == '.') {
        index = 11;
    } else if (ch == ':') {
        index = 12;
    } else if (ch == ' ') {
        index = 13;
    } else if (ch >= 'A' && ch <= 'Z') {
        switch(ch) {
            case 'P': index = 14; break;
            case 'E': index = 15; break;
            case 'M': index = 16; break;
            case 'T': index = 17; break;
            case 'U': index = 18; break;
            case 'K': index = 19; break;
            case 'H': index = 20; break;
            case 'D': index = 21; break;
            case 'C': index = 22; break;
            case 'L': index = 23; break;
            case 'N': index = 24; break;
            case 'R': index = 25; break;
            case 'S': index = 26; break;
            case 'A': index = 27; break;
            case 'B': index = 28; break;
            default: return;
        }
    } else if (ch >= 'a' && ch <= 'z') {
        ch = ch - 'a' + 'A';
        SSD1306_DrawChar(x, y, ch);
        return;
    } else {
        return;
    }

    const uint8_t* char_pixels = &font5x8[index * 5];
    for (uint8_t i = 0; i < 5; i++) {
        uint8_t line = char_pixels[i];
        for (uint8_t j = 0; j < 8; j++) {
            if (line & (1 << j)) {
                SSD1306_DrawPixel(x + i, y + j);
            }
        }
    }
}

// Function to print a string
void SSD1306_PrintString(uint8_t x, uint8_t y, const char* str) {
    uint8_t x_pos = x;
    while(*str) {
        SSD1306_DrawChar(x_pos, y, *str);
        x_pos += 6; // 5 pixels for character + 1 pixel space
        str++;

        // Wrap text if it reaches the end of the display
        if(x_pos > SSD1306_WIDTH - 6) {
            x_pos = 0;
            y += 9; // Move to next line (8 pixels height + 1 pixel space)
            if(y > SSD1306_HEIGHT - 8) break; // Stop if we reach bottom of screen
        }
    }
}

void float_to_string(float value, char* buffer, int precision) {
    int intPart = (int)value;
    float decPart = value - intPart;

    // Convert integer part
    int i = 0;
    if (intPart == 0) {
        buffer[i++] = '0';
    } else {
        int temp = intPart;
        while (temp > 0) {
            temp /= 10;
            i++;
        }
        temp = intPart;
        int j = i - 1;
        while (temp > 0) {
            buffer[j--] = '0' + (temp % 10);
            temp /= 10;
        }
    }

    // Add decimal point
    buffer[i++] = '.';

    // Convert decimal part
    for (int j = 0; j < precision; j++) {
        decPart *= 10;
        int digit = (int)decPart;
        buffer[i++] = '0' + digit;
        decPart -= digit;
    }

    buffer[i] = '\0';
}

uint8_t get_string_length(const char* str) {
    uint8_t length = 0;
    while(str[length] != '\0') {
        length++;
    }
    return length;
}

// Function to calculate horizontal center position for text
uint8_t get_center_position_x(const char* str) {
    uint8_t length = get_string_length(str);
    // Each character is 6 pixels wide (5 pixels + 1 space)
    uint8_t string_width = length * 6;
    // Center position = (display width - string width) / 2
    if (string_width >= SSD1306_WIDTH) {
        return 0;
    }
    return (SSD1306_WIDTH - string_width) / 2;
}

// Modified function to draw a custom symbol
void SSD1306_DrawSymbol(uint8_t x, uint8_t y, uint8_t symbol_index) {
    // Each symbol is 8 bytes (8x8 pixels)
    const uint8_t* symbol_pixels = &custom_symbols[symbol_index * 8];

    // Draw the 8x8 symbol
    for (uint8_t i = 0; i < 8; i++) {
        uint8_t line = symbol_pixels[i];
        for (uint8_t j = 0; j < 8; j++) {
            if (line & (1 << (7-j))) {  // MSB first
                SSD1306_DrawPixel(x + j, y + i);
            }
        }
    }
}


// Get time string function
void get_time_string(char* buffer) {
    sprintf(buffer, "%02d:%02d", current_hours, current_minutes);
}

uint8_t get_random_bpm() {
    return 78 + (rand() % 23); // Random value between 78-100 for BPM
}

void display_all_parameters_OLED(float temp_value, uint16_t steps) {
    char float_buffer[16];
    char display_buffer[32];
    char time_buffer[6];
    uint8_t text_x;

    SSD1306_Clear();

    // Time at top
    get_time_string(time_buffer);
    text_x = (SSD1306_WIDTH - (strlen(time_buffer) * 6)) / 2;
    SSD1306_PrintString(text_x, 0, time_buffer);

    // Temperature line (moved down)
    float_to_string(temp_value, float_buffer, 2);
    strcpy(display_buffer, "TEMP: ");
    strcat(display_buffer, float_buffer);
    text_x = (SSD1306_WIDTH - (strlen(display_buffer) * 6)) / 2;

    // Draw temperature symbol and text with more space
    SSD1306_DrawSymbol(text_x - 12, 16, 0);  // Temperature symbol
    SSD1306_PrintString(text_x, 16, display_buffer);

    sprintf(display_buffer, "STEPS: %u", steps);
    text_x = (SSD1306_WIDTH - (strlen(display_buffer) * 6)) / 2;

    // Draw steps symbol and text with more space
    SSD1306_DrawSymbol(text_x - 12, 32, 1);  // Steps symbol
    SSD1306_PrintString(text_x, 32, display_buffer);

    // BPM line
    uint8_t bpm = get_random_bpm();
    sprintf(display_buffer, "BPM: %u", bpm);
    text_x = (SSD1306_WIDTH - (strlen(display_buffer) * 6)) / 2;

    // Draw heart symbol and text with more space
    SSD1306_DrawSymbol(text_x - 12, 48, 2);  // Heart symbol
    SSD1306_PrintString(text_x, 48, display_buffer);

    SSD1306_UpdateDisplay();
}

//volatile uint32_t currentSteps = 0;

//// Example interrupt handler (implement in your main application)
//void GPIO_EVEN_IRQHandler(void) {
//  uint32_t flags = GPIO_IntGet();
//
//      if (flags & (1 << BMA400_GPIO_PIN)) {
//          if (BMA400_isStepDetected()) {
//            // A new step has been detected
//            // Add your step processing code here
//            currentSteps = BMA400_readStepCount();
//
//            // Clear the interrupt status by reading it
//            (void)I2C_readByte(BMA400_I2C_ADDRESS, BMA400_INT_STATUS);
//        }
//    }
//
//    uart_send_string("INT\r\n");
//
//    GPIO_IntClear(flags);
//}
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
int main(void)
{
  sl_system_init();
  uart_init();
  uart_send_string("Code starting Now \r\n");
  timer_init();
  I2C_init();
  blocking_delay_ms(100);


  uint8_t errorCode = BMA400_init();
  if(errorCode != 0x90) {
      uart_send_number(errorCode);
      uart_send_string("Chip ID not matched !!\r\n");
      return 1;
  }

  BMA400_initStepCounter();

  // Verify configuration
  if (!BMA400_verifyConfiguration()) {
      uart_send_string("BMA400 configuration failed!\r\n");
  }

//  BMA400_enableStepInterrupt();
//  BMA400_configureGPIOInterrupt();

  uart_send_string("Reading values from Sensors:\r\n");
  //timer_init();
  blocking_delay_ms(1000);
  float x, y, z;
  floatToStr(-7.82, buffer, 2);
  uart_send_string(buffer);
  uart_send_string("\r\n");

  //uint16_t steps = 0;
  float temperatureC = 29.0;

  SSD1306_Init();

      SSD1306_ClearDisplay();

         // Draw test pattern
         SSD1306_DrawTestPattern();


  while (1) {
      BMA400_readAccel(&x, &y, &z);
      uint32_t steps = BMA400_readStepCount();
      floatToStr(steps, buffer, 2);
      uart_send_string("steps :");
      uart_send_string(buffer);

//      floatToStr(y, buffer, 2);
//      uart_send_string(", y:");
//      uart_send_string(buffer);
//
//      floatToStr(z, buffer, 2);
//      uart_send_string(", z:");
//      uart_send_string(buffer);

      uart_send_string("\r\n");
      blocking_delay_ms(500);

      uint16_t temperatureRaw = i2c_read_temperature();
      if (temperatureRaw != 0xFFFF) {
           temperatureC = convertToCelsius(temperatureRaw);
           floatToStr(temperatureC, buffer, 2);
           uart_send_string("Temperature: ");
           uart_send_string(buffer);
           uart_send_string("\r\n");
         }

      //steps = (uint16_t) x;
      display_all_parameters_OLED(temperatureC, steps);
      blocking_delay_ms(2000);
  }
 }

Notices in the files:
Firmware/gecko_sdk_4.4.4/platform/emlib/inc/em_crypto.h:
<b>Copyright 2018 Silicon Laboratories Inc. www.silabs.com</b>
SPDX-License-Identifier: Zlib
